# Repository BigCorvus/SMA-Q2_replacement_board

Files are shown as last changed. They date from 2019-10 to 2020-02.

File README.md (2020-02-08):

# SMA-Q2_replacement_board
SMA-Q2_replacement_board
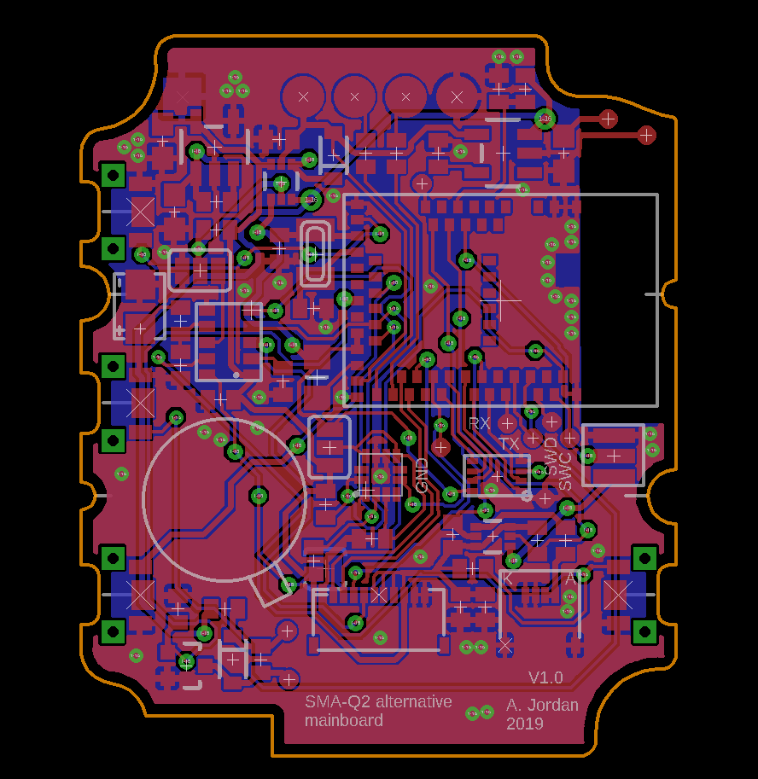
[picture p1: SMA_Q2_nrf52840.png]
SMA-Q2_replacement_board

Custom replacement board with an nrf52840 module based on the feather board. It features a https://abracon.com/realtimeclock/AB-RTCMC-32.768kHz-IBO5-S3.pdf RTC with a tiny superca for timekeeping. It will take care of generating the extcomin signal and minute-wise updates of the display. In between the updates the MCU can be turned off completely which can lead to very low  overall power consumption of the watch. That way one can just write Sketches for the nrf52840 without having to engineer low power stuff, so one should have a reliable device capable for everyday use. You have native USB for DFU und other communication via the charging cable which has a USB plug connected to the  four contacts anyway. The accelerometer is a BMA400 and the heart rate sensor based on https://pulsesensor.com sitting on a custom flex PCB connected to an analog input: https://github.com/BigCorvus/PulseSensor-for-SMA-Q2/tree/master

The current version snapfits almost perfectly into the LCD frame. Had to file a corner for a fraction of a millimeter.

The BOM is not quite finished yet because I have not setteled on the final component values, but most of them should be straightforward. Just consult the schematc. 
The dual P-Channel mosfets might be CMLDM8005 TR PBFREE (Digikey 1514-CMLDM8005TRPBFREECT-ND). 
Pushbuttons are LS12T2-T (Digikey 1642-1312-1-ND).
The supercap is Seiko CPH3225A (728-1127-1-ND). 
The RTC is Abracon AB-RTCMC-32.768kHz-IBO5-S3 (535-13301-1-ND). 
The display connectors are 255-3056-1-ND and 255-5667-ND. 
Accelerometer is 828-1081-1-ND (BMA400). 
Schottky diodes are 497-7163-1-ND. 
Flash chip is 1970-1011-1-ND. 
LDO is 296-24059-1-ND. 
The BT module is a Raytac MDBT50Q (1597-1678-ND). 
Watch crystal: 478-5428-1-ND. 
Mosfet for vibrator is DMG1012UW-7DICT-ND.
LED for HR sensor: 1497-1162-1-ND, Opamp: MCP6001T-I/LTCT-ND.
The vibration motor is 8mm in diameter and 2mm high. Can be found on Aliexpress.  
  
Newer version: https://github.com/BigCorvus/SMA-Q2_replacement_board_v2  
Arduino Firmware: https://github.com/BigCorvus/SMA-Q2-nrf52840-dualMode-firmware

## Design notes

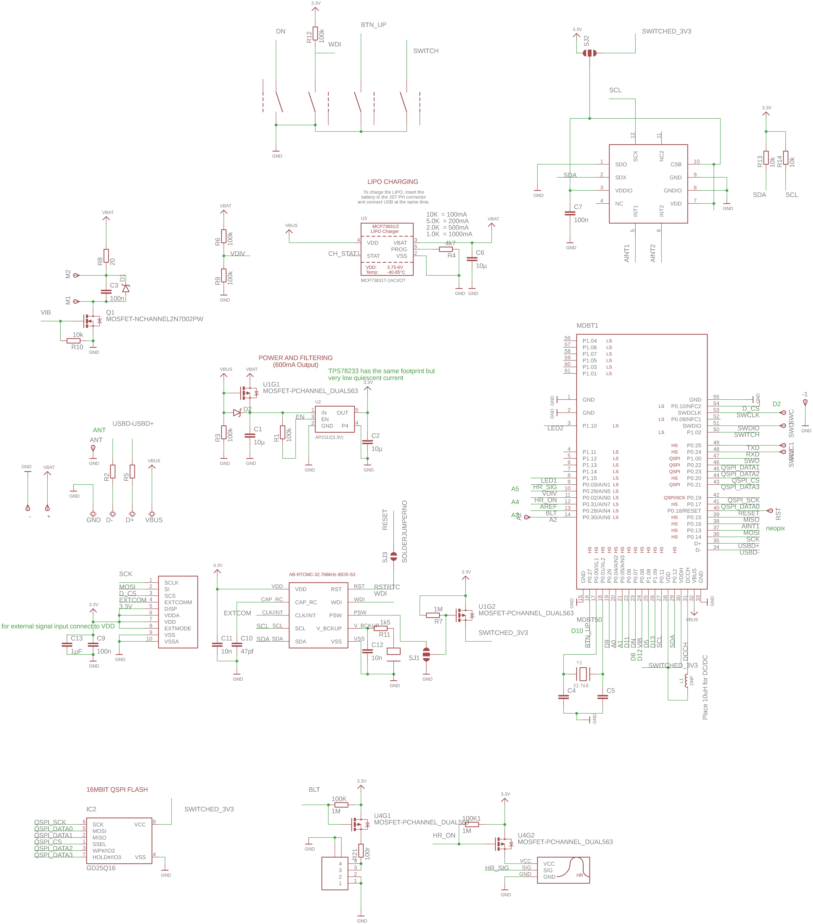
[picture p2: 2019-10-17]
SMA-Q2_nrf52840.png

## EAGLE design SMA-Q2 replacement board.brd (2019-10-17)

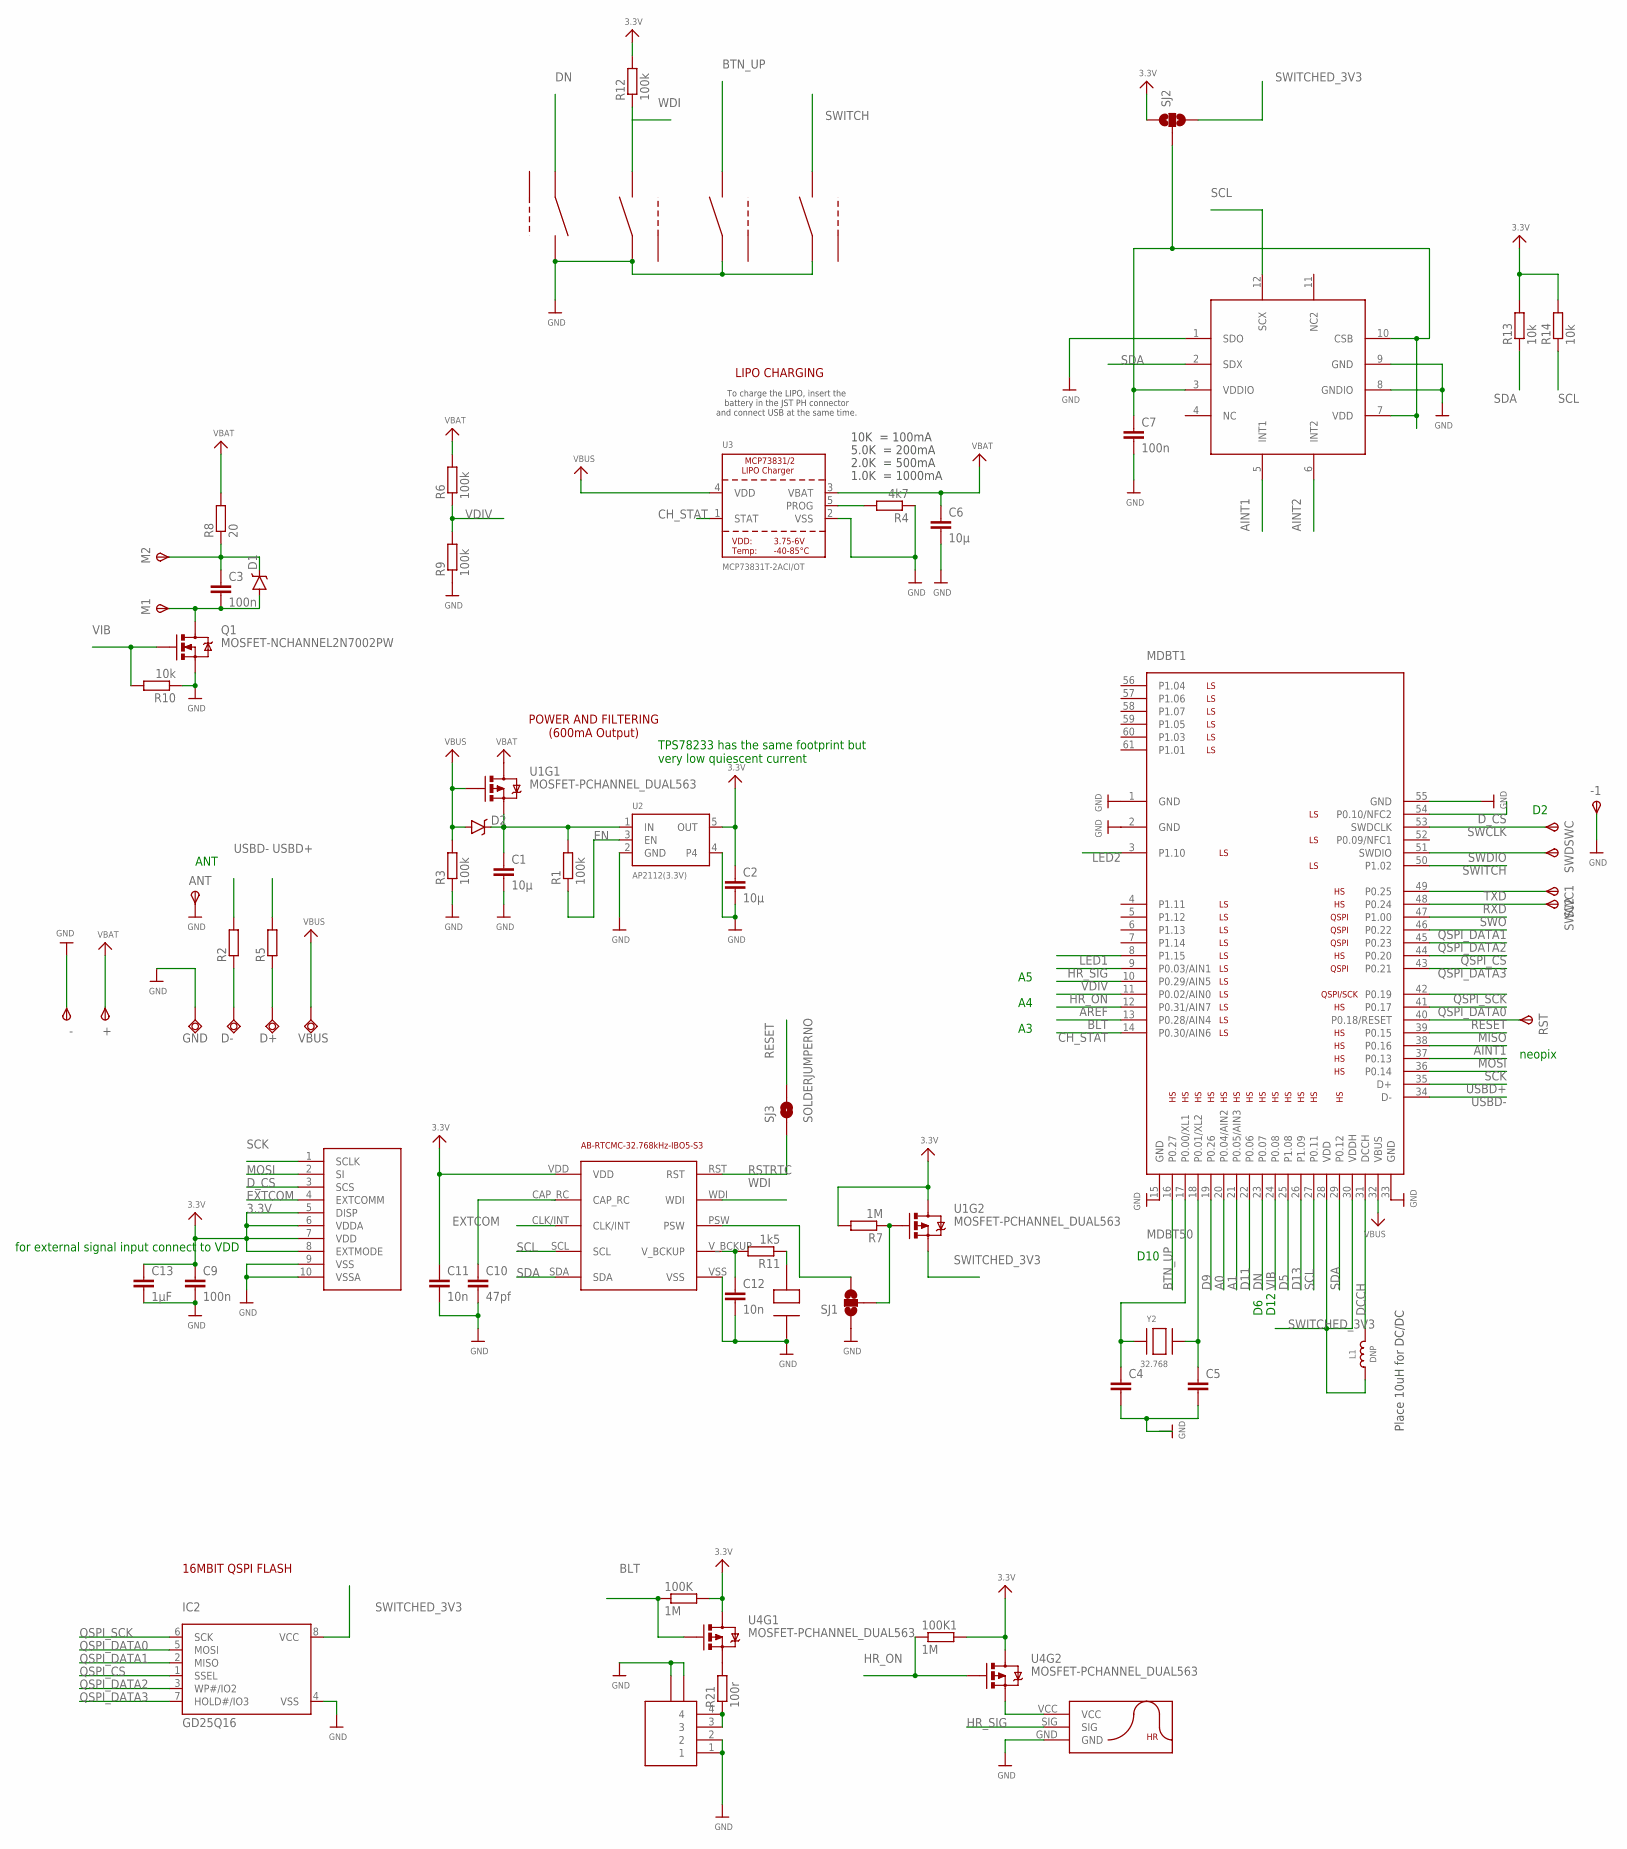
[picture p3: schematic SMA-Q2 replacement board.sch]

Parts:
100K, 100K1: 1M; R0402
+: TPSTP09R; TP09R
-, -1: TPSTP09R; TP09R
ANT: TPSTP19SQ; TP19SQ
C1, C2, C6: 10µ; C0603
C3, C7, C9: 100n; C0402
C4, C5: C-EUC0402; C0402
C10: 47pf; C0402
C11, C12: 10n; C0402
C13: 1µF; C0402
D1, D2: BAT20J; SOD-323
D+: TPSQTP20R; TP20R
D-: TPSQTP20R; TP20R
DWN, DWN1, DWN2, DWN3: LS12T2
GND: TPSQTP20R; TP20R
IC2: GD25Q16; USON8
L1: DNP; _0805MP
M1, M2: TPSTP09R; TP09R
MDBT1: MDBT50
Q1: MOSFET-NCHANNEL2N7002PW; SOT323
R1, R3, R6, R9, R12: 100k; R0402
R2, R5: R-EU_R0402; R0402
R4: 4k7; R0402
R7: 1M; R0402
R8: 20; R0402
R10, R13, R14: 10k; R0402
R11: 1k5; R0402
R21: 100r; R0402
RST: TPSTP09R; TP09R
SJ1, SJ2: SOLDERJUMPER_2WAYS; SJ_3
SJ3: SOLDERJUMPERNO; SJ_2S-NO
SWC, SWC1, SWC2: TPSTP09R; TP09R
SWD: TPSTP09R; TP09R
U1, U4: MOSFET-PCHANNEL_DUAL563; SOT563
U2: AP2112(3.3V); SOT23-5
U3: MCP73831T-2ACI/OT; SOT23-5
U$1: AB-RTCMC-32.768KHZ-IBO5-S3
U$2: SHARP_MEM_DISP; Y5BW
U$6: Y5B-4PIN
U$7: BMA400
U$15: CPH3225A
U$45: HR_PADS
VBUS: TPSQTP20R; TP20R
Y2: 32.768; XTAL3215

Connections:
3.3V: 100K.2, 100K1.2, C2.1, C9.1, C11.1, C13.1, R7.2, R12.2, R13.2, R14.2, SJ2.1, U1.D2 (D), U2.5 (OUT), U4.D1 (D), U4.D2 (D), U$1.VDD, U$2.5 (DISP), U$2.6 (VDDA), U$2.7 (VDD), U$2.8 (EXTMODE)
A0: MDBT1.20 (P0.04/AIN2)
A1: MDBT1.21 (P0.05/AIN3)
AINT1: MDBT1.38 (P0.16), U$7.5 (INT1)
AINT2: U$7.6 (INT2)
AREF: MDBT1.12 (P0.31/AIN7)
BLT: 100K.1, MDBT1.13 (P0.28/AIN4), U4.G1 (G)
BTN_UP: DWN2.1, MDBT1.16 (P0.27)
CH_STAT: MDBT1.14 (P0.30/AIN6), U3.1 (STAT)
D5: MDBT1.25 (P1.08)
D9: MDBT1.19 (P0.26)
D11: MDBT1.22 (P0.06)
D13: MDBT1.26 (P1.09)
DCCH: L1.2, MDBT1.31 (DCCH)
DN: DWN.2, MDBT1.23 (P0.07)
D_CS: MDBT1.54 (P0.10/NFC2), U$2.3 (SCS)
EN: R1.1, U2.3 (EN)
EXTCOM: U$1.CLK/INT, U$2.4 (EXTCOMM)
GND: -.TP, -1.TP, ANT.TP, C1.2, C2.2, C4.2, C5.2, C6.2, C7.2, C9.2, C10.2, C11.2, C12.2, C13.2, DWN.1, DWN1.2, DWN2.2, DWN3.2, GND.TP, IC2.4 (VSS), MDBT1.1 (GND), MDBT1.2 (GND), MDBT1.15 (GND), MDBT1.33 (GND), MDBT1.55 (GND), Q1.2 (S), R3.1, R4.1, R9.1, R10.1, SJ1.1, U2.2 (GND), U2.4, U3.2 (VSS), U$1.VSS, U$2.9 (VSS), U$2.10 (VSSA), U$6.1, U$6.2, U$6.H1, U$6.H2, U$7.1 (SDO), U$7.8 (GNDIO), U$7.9 (GND), U$15.-, U$45.GND
HR_ON: 100K1.1, MDBT1.11 (P0.02/AIN0), U4.G2 (G)
HR_SIG: MDBT1.9 (P0.03/AIN1), U$45.SIG
LED1: MDBT1.8 (P1.15)
LED2: MDBT1.3 (P1.10)
MISO: MDBT1.39 (P0.15)
MOSI: MDBT1.37 (P0.13), U$2.2 (SI)
unnamed: R7.1, SJ1.2, U1.G2 (G)
unnamed: C10.1, U$1.CAP_RC
unnamed: D-.TP, R2.1
unnamed: D+.TP, R5.1
unnamed: C7.1, SJ2.2, U$7.3 (VDDIO), U$7.7 (VDD), U$7.10 (CSB)
unnamed: SJ1.3, U$1.PSW
unnamed: C4.1, MDBT1.17 (P0.00/XL1), Y2.P$1
unnamed: C5.1, MDBT1.18 (P0.01/XL2), Y2.P$2
unnamed: R21.1, U$6.3, U$6.4
unnamed: C12.1, R11.2, U$1.V_BCKUP
unnamed: R11.1, U$15.+
unnamed: R4.2, U3.5 (PROG)
unnamed: C3.2, D1.A, M1.TP, Q1.3 (D)
unnamed: C3.1, D1.C, M2.TP, R8.1
unnamed: U4.S2 (S), U$45.VCC
unnamed: R21.2, U4.S1 (S)
QSPI_CS: IC2.1 (SSEL), MDBT1.44 (P0.20)
QSPI_DATA0: IC2.5 (MOSI), MDBT1.41 (P0.17)
QSPI_DATA1: IC2.2 (MISO), MDBT1.46 (P0.22)
QSPI_DATA2: IC2.3 (WP#/IO2), MDBT1.45 (P0.23)
QSPI_DATA3: IC2.7 (HOLD#/IO3), MDBT1.43 (P0.21)
QSPI_SCK: IC2.6 (SCK), MDBT1.42 (P0.19)
RESET: MDBT1.40 (P0.18/RESET), RST.TP, SJ3.2
RSTRTC: SJ3.1, U$1.RST
RXD: MDBT1.48 (P0.24), SWC2.TP
SCK: MDBT1.36 (P0.14), U$2.1 (SCLK)
SCL: MDBT1.27 (P0.11), R14.1, U$1.SCL, U$7.12 (SCX)
SDA: MDBT1.29 (P0.12), R13.1, U$1.SDA, U$7.2 (SDX)
SWCLK: MDBT1.53 (SWDCLK), SWC.TP
SWDIO: MDBT1.51 (SWDIO), SWD.TP
SWITCH: DWN3.1, MDBT1.50 (P1.02)
SWITCHED_3V3: IC2.8 (VCC), L1.1, MDBT1.28 (VDD), MDBT1.30 (VDDH), SJ2.3, U1.S2 (S)
SWO: MDBT1.47 (P1.00)
TXD: MDBT1.49 (P0.25), SWC1.TP
USBD+: MDBT1.35 (D+), R5.2
USBD-: MDBT1.34 (D-), R2.2
VBAT: +.TP, C6.1, R6.2, R8.2, U1.D1 (D), U3.3 (VBAT)
VBUS: D2.A, MDBT1.32 (VBUS), R3.2, U1.G1 (G), U3.4 (VDD), VBUS.TP
VDIV: MDBT1.10 (P0.29/AIN5), R6.1, R9.2
VHI: C1.1, D2.C, R1.2, U1.S1 (S), U2.1 (IN)
VIB: MDBT1.24 (P0.08), Q1.1 (G), R10.2
WDI: DWN1.1, R12.1, U$1.WDI

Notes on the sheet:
Place 10uH for DC/DC
10K = 100mA
5.0K = 200mA
2.0K = 500mA
1.0K = 1000mA
LIPO CHARGING
To charge the LIPO, insert the battery in the JST PH connector and connect USB at the same time.
POWER AND FILTERING (600mA Output)
ANT
TPS78233 has the same footprint but very low quiescent current
16MBIT QSPI FLASH
for external signal input connect to VDD
D10
D12
neopix

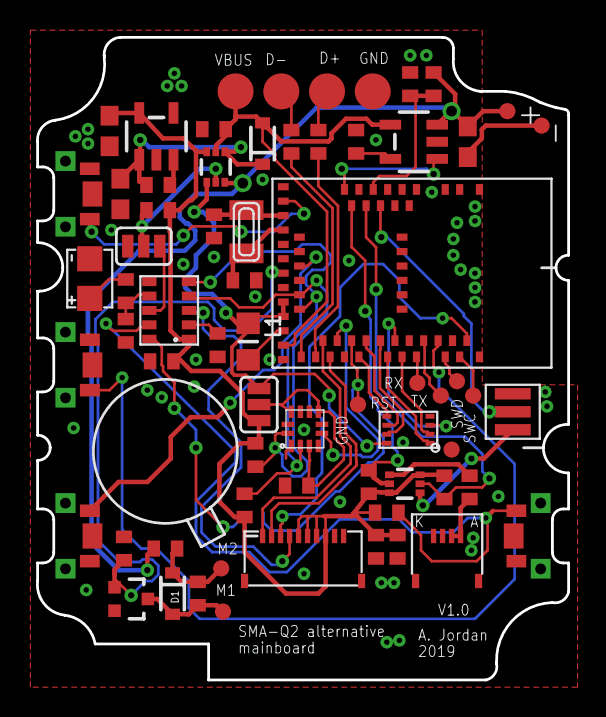
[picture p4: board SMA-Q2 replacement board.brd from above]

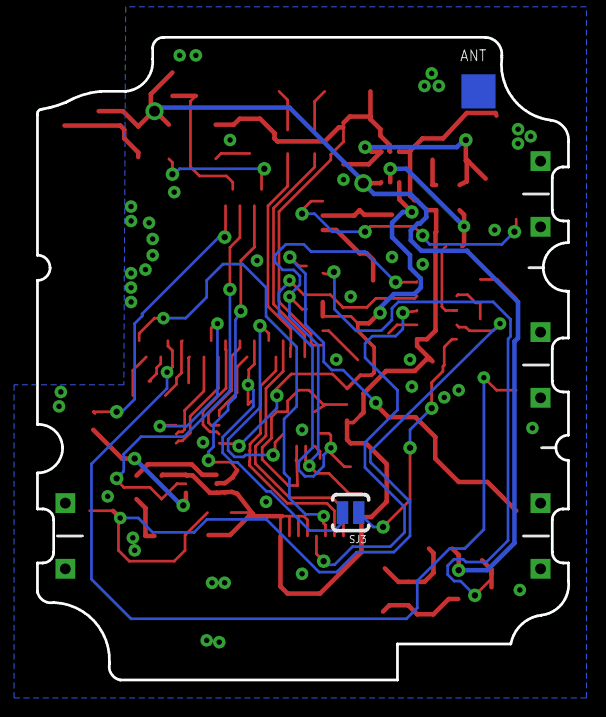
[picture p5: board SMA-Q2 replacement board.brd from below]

Board: 2 copper layers, 29.5 x 35.7 mm, 68 parts (2 on the bottom side), 55 nets.

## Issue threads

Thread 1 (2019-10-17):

BOM

scientistnobee, 2019-10-17:
Hi,

Very cool project.
Could you please add bill of the materials.

BigCorvus, 2019-10-17:
Hi,
Sorry I haven't figured out all component values yet. The P-Channel mosfets I'm using at the moment are the wrong ones for example. I'll add a BOM as soon as I'm pleased with the chosen components. Most values are at least in the right ballpark. Just check the schematic...
--
Diese Nachricht wurde von meinem Android Mobiltelefon mit WEB.DE Mail gesendet.Am 17.10.19, 15:35, scientistnobee <notifications@github.com> schrieb:
Hi,
Very cool project.
Could you please add bill of the materials.

—You are receiving this because you are subscribed to this thread.Reply to this email directly, view it on GitHub, or unsubscribe.
[
{
"@context": "http://schema.org",
"@type": "EmailMessage",
"potentialAction": {
"@type": "ViewAction",
"target": "https://github.com/BigCorvus/SMA-Q2_replacement_board/issues/1?email_source=notifications\u0026email_token=AGCSKDHE7DRDR5R4RJWLNSDQPBS25A5CNFSM4JBZW72KYY3PNVWWK3TUL52HS4DFUVEXG43VMWVGG33NNVSW45C7NFSM4HSOZMTQ",
"url": "https://github.com/BigCorvus/SMA-Q2_replacement_board/issues/1?email_source=notifications\u0026email_token=AGCSKDHE7DRDR5R4RJWLNSDQPBS25A5CNFSM4JBZW72KYY3PNVWWK3TUL52HS4DFUVEXG43VMWVGG33NNVSW45C7NFSM4HSOZMTQ",
"name": "View Issue"
},
"description": "View this Issue on GitHub",
"publisher": {
"@type": "Organization",
"name": "GitHub",
"url": "https://github.com"
}
}
]

BigCorvus, 2019-10-18:
Hi,

I listed the most important components now. The passives should be self-explanatory.

The dual P-Channel mosfets might be CMLDM8005 TR PBFREE (Digikey 1514-CMLDM8005TRPBFREECT-ND)

pushbuttons are LS12T2-T (Digikey 1642-1312-1-ND).

The supercap is Seiko CPH3225A (728-1127-1-ND),

the RTC is Abracon AB-RTCMC-32.768kHz-IBO5-S3 (535-13301-1-ND),

The display connectors are 255-3056-1-ND and 255-5667-ND.

Accelerometer is 828-1081-1-ND (BMA400),

Schottky Diodes are 497-7163-1-ND,

Flash chip is 1970-1011-1-ND.

LDO is 296-24059-1-ND.

The BT module is a Raytac MDBT50Q (1597-1678-ND),

Watch crystal: 478-5428-1-ND,

Mosfet for vibrator is DMG1012UW-7DICT-ND.

LED for HR sensor: 1497-1162-1-ND,

Opamp: MCP6001T-I/LTCT-ND

Gesendet: Donnerstag, 17. Oktober 2019 um 15:35 Uhr
Von: "scientistnobee" <notifications@github.com>
An: BigCorvus/SMA-Q2_replacement_board <SMA-Q2_replacement_board@noreply.github.com>
Cc: Subscribed <subscribed@noreply.github.com>
Betreff: [BigCorvus/SMA-Q2_replacement_board] BOM (#1)

Hi,

Very cool project.
Could you please add bill of the materials.

—
You are receiving this because you are subscribed to this thread.
Reply to this email directly, view it on GitHub, or unsubscribe.

scientistnobee, 2019-10-18:
Thanks for the update

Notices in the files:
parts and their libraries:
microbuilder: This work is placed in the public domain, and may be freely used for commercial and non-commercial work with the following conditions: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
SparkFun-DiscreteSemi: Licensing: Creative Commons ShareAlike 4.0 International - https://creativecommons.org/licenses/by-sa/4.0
